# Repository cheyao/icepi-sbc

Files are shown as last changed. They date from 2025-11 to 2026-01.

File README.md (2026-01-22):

# Icepi SBC

A low-cost single-board computer for the H3 CPU: A cheap yet powerful Linux device that you can take anywhere.

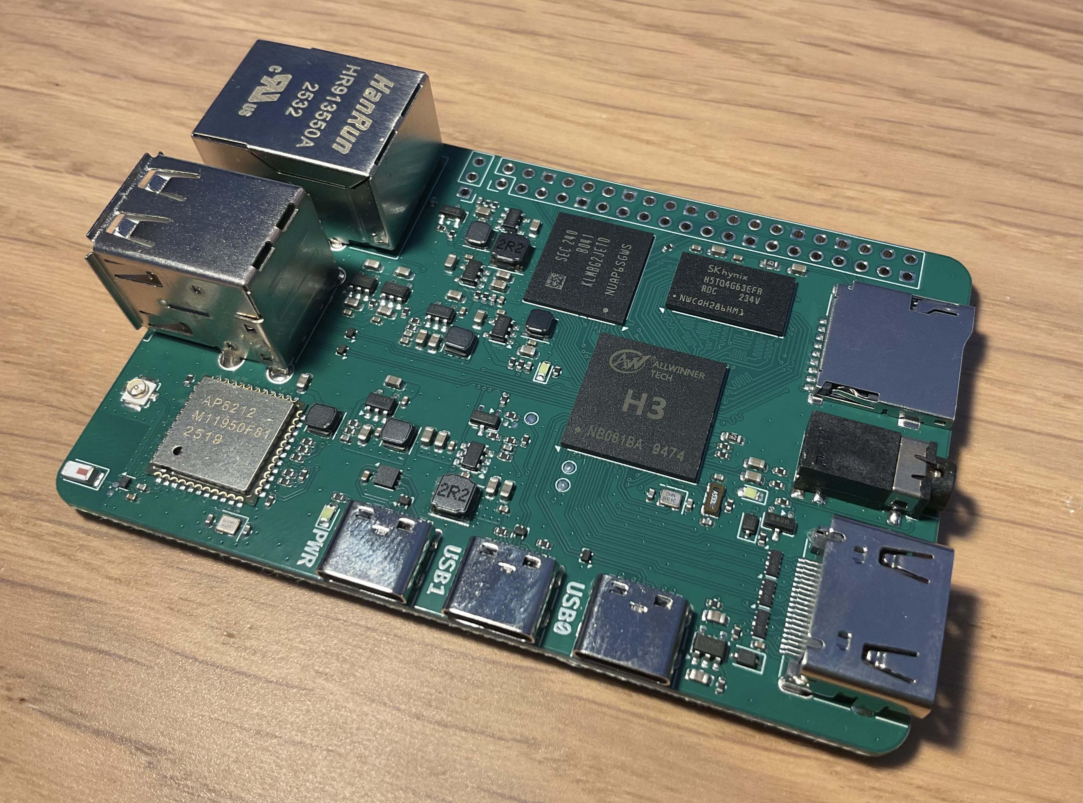
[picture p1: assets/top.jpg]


| Interested? [Subscribe to updates!](https://cyao.dev/subscribe.html) | Check out [Icepi Zero](https://github.com/cheyao/icepi-zero) too |
| --- | --- |

If there's a lot of people interested, there's a chance that I'll try to sell this at a relatively low price :P

## Features

- H3 Quad-Core ARM Cortex-A7 @ 1.296GHz CPU
    - Mali400 MP2 OpenGL ES 2.0 GPU
- 512MiB of DDR3 RAM, stable at 696MHz (Upgradable to 1GiB)
- Ethernet PHY, WiFi & Bluetooth
- GPDI video out
- USB connectors:
    - 2x USB-A 
    - 2x USB-C (One OTG port)
    - 1x USB-C 100W PD power port
- 3.5mm audio jack
- uSD card slot
- eMMC 5.1 storage



## System support

The single-board computer is capable of running Linux (debian) and Android ([H3Droid](https://h3droid.com/project)). It can output 4k video via it's GPDI-A connector, output a tty consol via UART, or act as an remote host via ssh.

It's small, compact form factor allows it to be a nice portable computer that you can take anywhere! It supports GPU acceleration and 4k video decoding, letting you view anything in full confort.

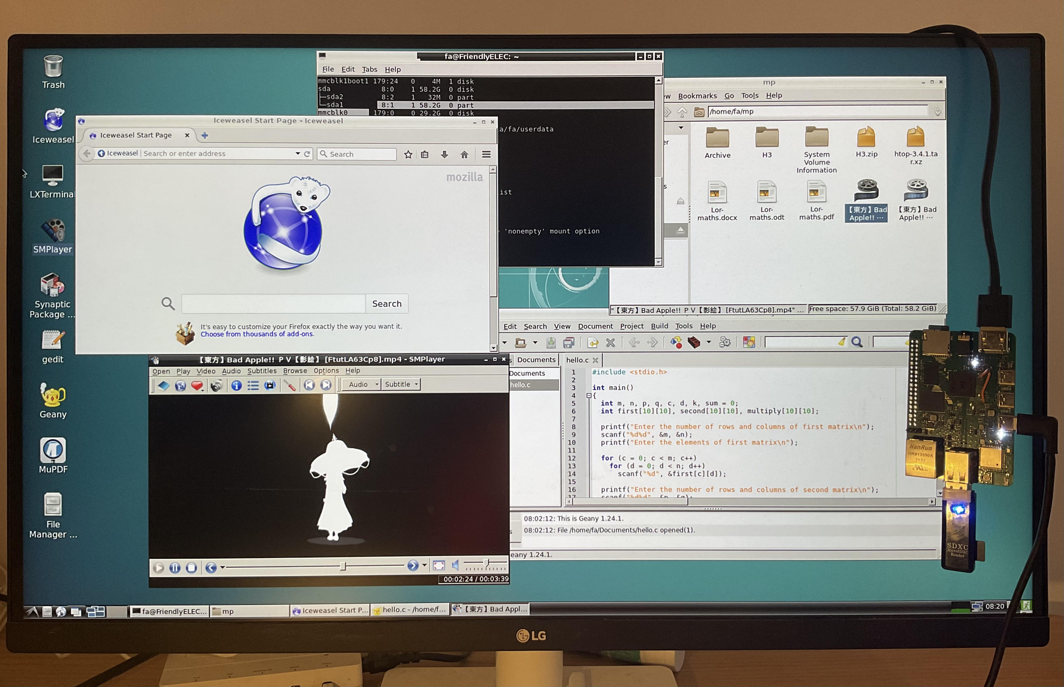
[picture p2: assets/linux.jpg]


## PCB

[Check out the online version here](https://github.com/cheyao/icepi-sbc/tree/main/hardware).

The PCB is only 4 layered, ensuring minimal cost and overhead during production. But for mass production 6 layers is recommended, putting solid ground on In.1 and In.4, then copy the power plane to In.2 and In.3. (Impedance matching might be required depending on stackup)

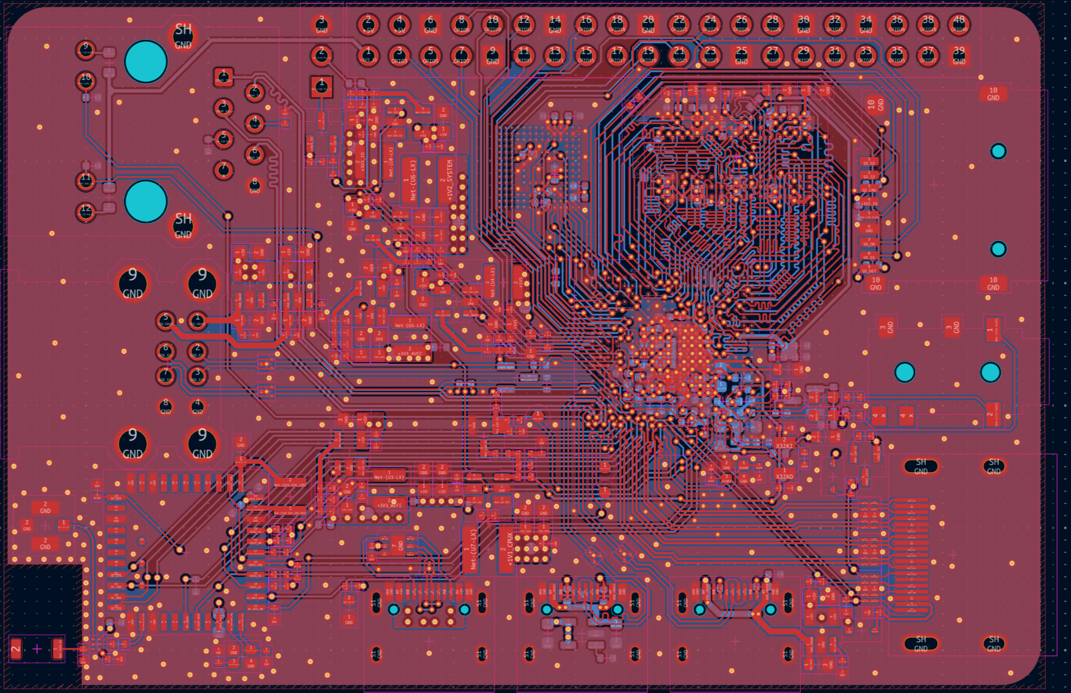
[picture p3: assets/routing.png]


The current setup uses [JLCPCB's](https://jlcpcb.com/) JLC04161H-3313 stackup, and the BOM is optimized for use there. Using other fabs would require re-tuning the DDR3, USB and GPDI traces.

## Open source

This project is licensed under the [Solderpad](/LICENSE) hardware license, granting the maximum amount of liberty :)

It is also OSHWA certified under the identifier [FR000029](https://certification.oshwa.org/fr000029.html).

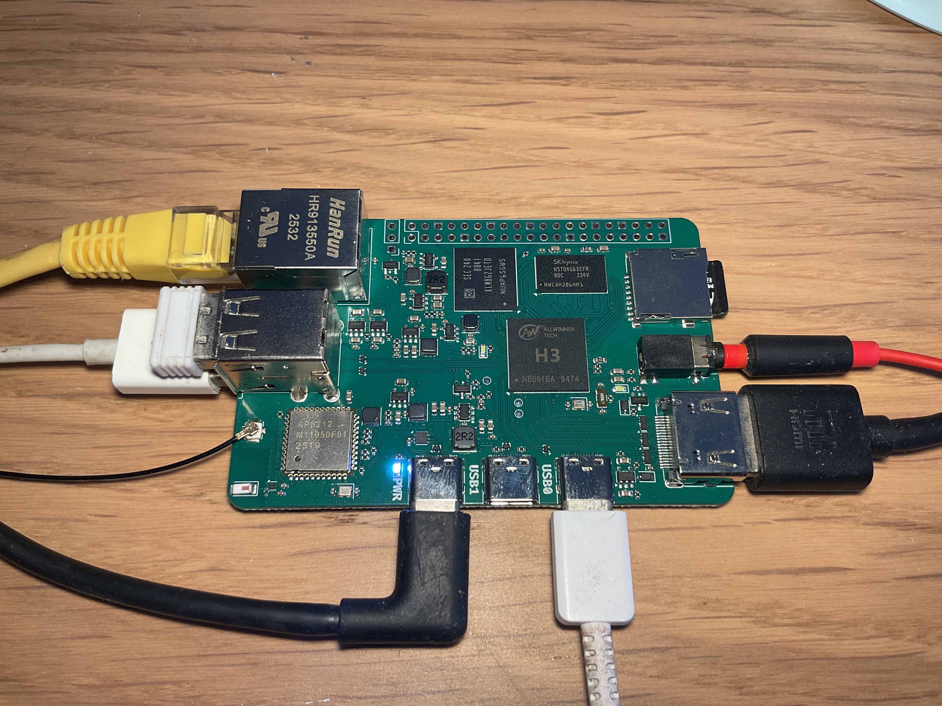
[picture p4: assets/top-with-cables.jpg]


## Contact

Any questions? Dm `@Cyao.` on Discord (Send a friend request or join the KiCAD Discord server) or send an email to `cyao _at_ duck.com`!

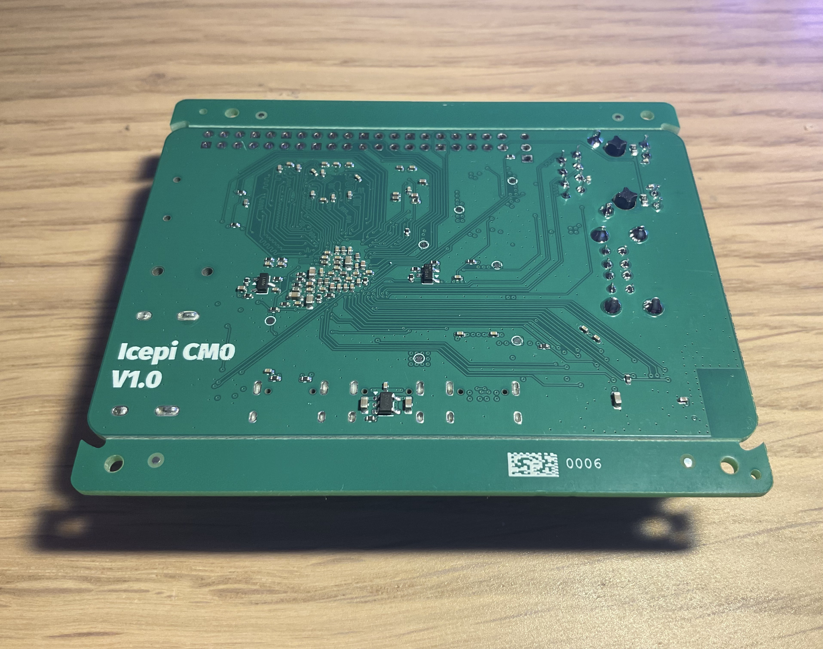
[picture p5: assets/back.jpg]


## Bonus

POV: Running Android on the single board computer to study Eigenvectors in the middle of the night:

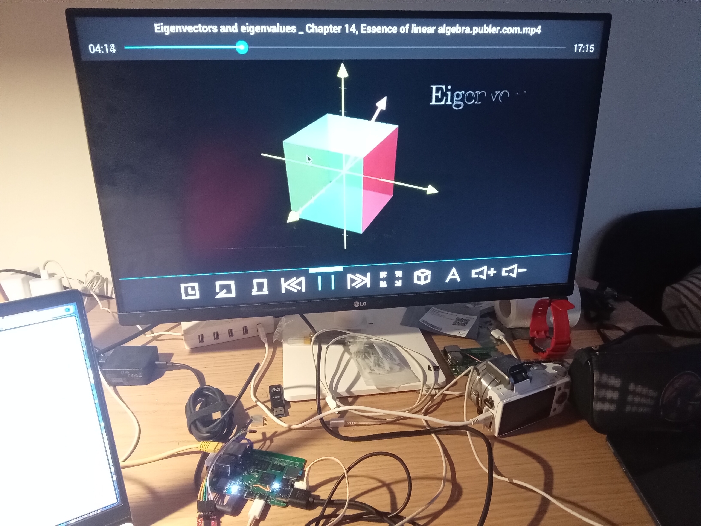
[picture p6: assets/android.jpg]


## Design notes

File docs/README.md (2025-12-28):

# Usage

To power up the board, plug a USB-C cable into the port labeled PWR.

The SBC can boot either from a SD-Card, or the eMMC.

## Linux

This board should be compatiable with the Orange Pi Linux images! But I might make my own Linux image when I get my hands on the boards.

## Android

Check out the https://www.h3droid.com/ project! I'll try and port it over when I have time.

## Debugging

You can find the UART pins on the top-left corner of the PCB, in the up-to-down order of GND, TX, RX.

The CPU's debug software and manual can be downloaded [here](https://mega.nz/folder/dRNDiaLS#P0zxg4pFopMfrBjBBBc2VA).

## More info

You can find more info about the H3 processor here:

https://linux-sunxi.org/H3

## License

The hardware is licensed under the [solderpad](https://solderpad.org/licenses/) license, and the documentation under [zlib](https://en.wikipedia.org/wiki/Zlib_License).

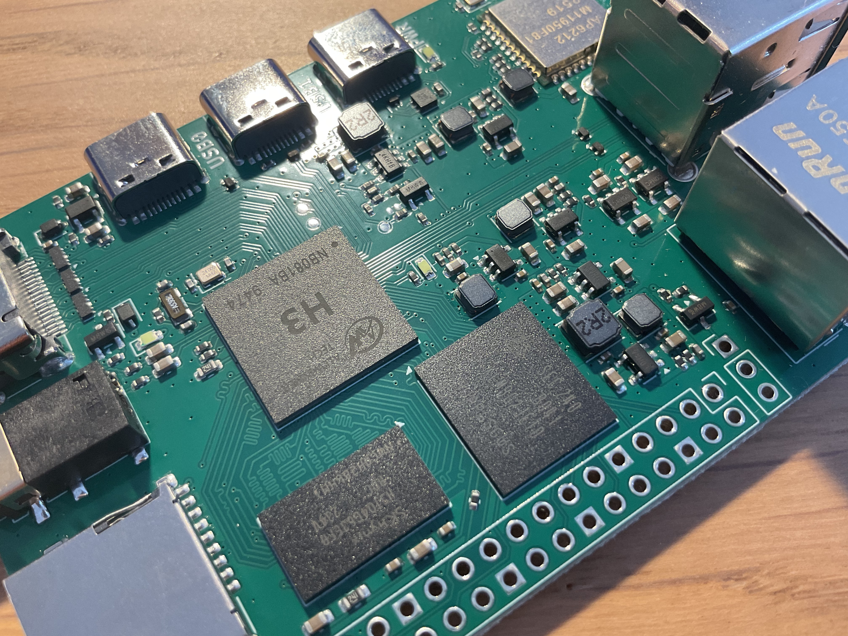
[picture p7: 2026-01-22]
assets/chip-zoom.jpg

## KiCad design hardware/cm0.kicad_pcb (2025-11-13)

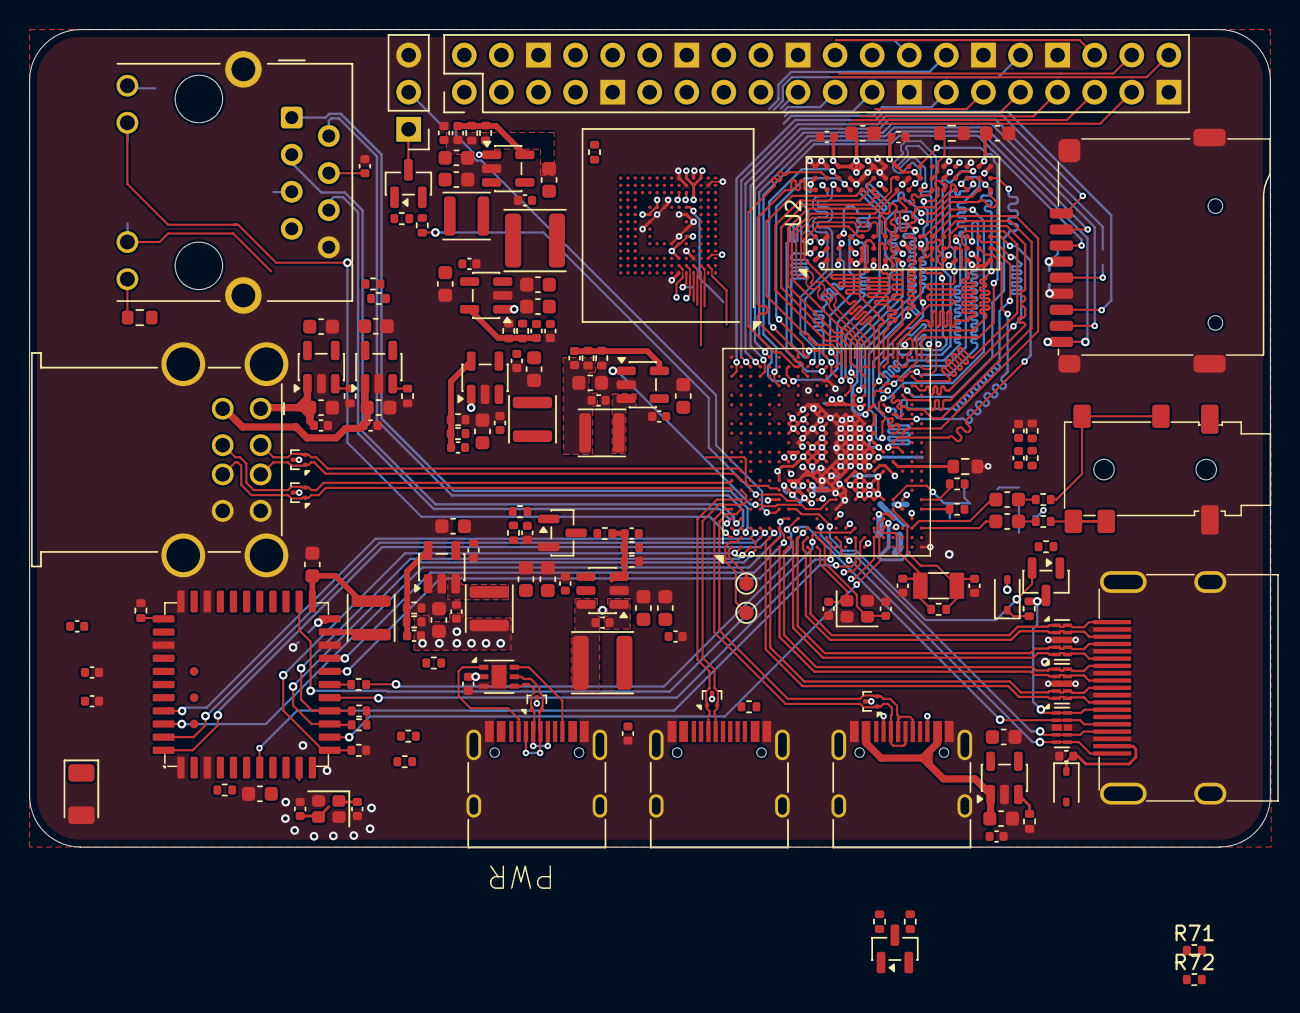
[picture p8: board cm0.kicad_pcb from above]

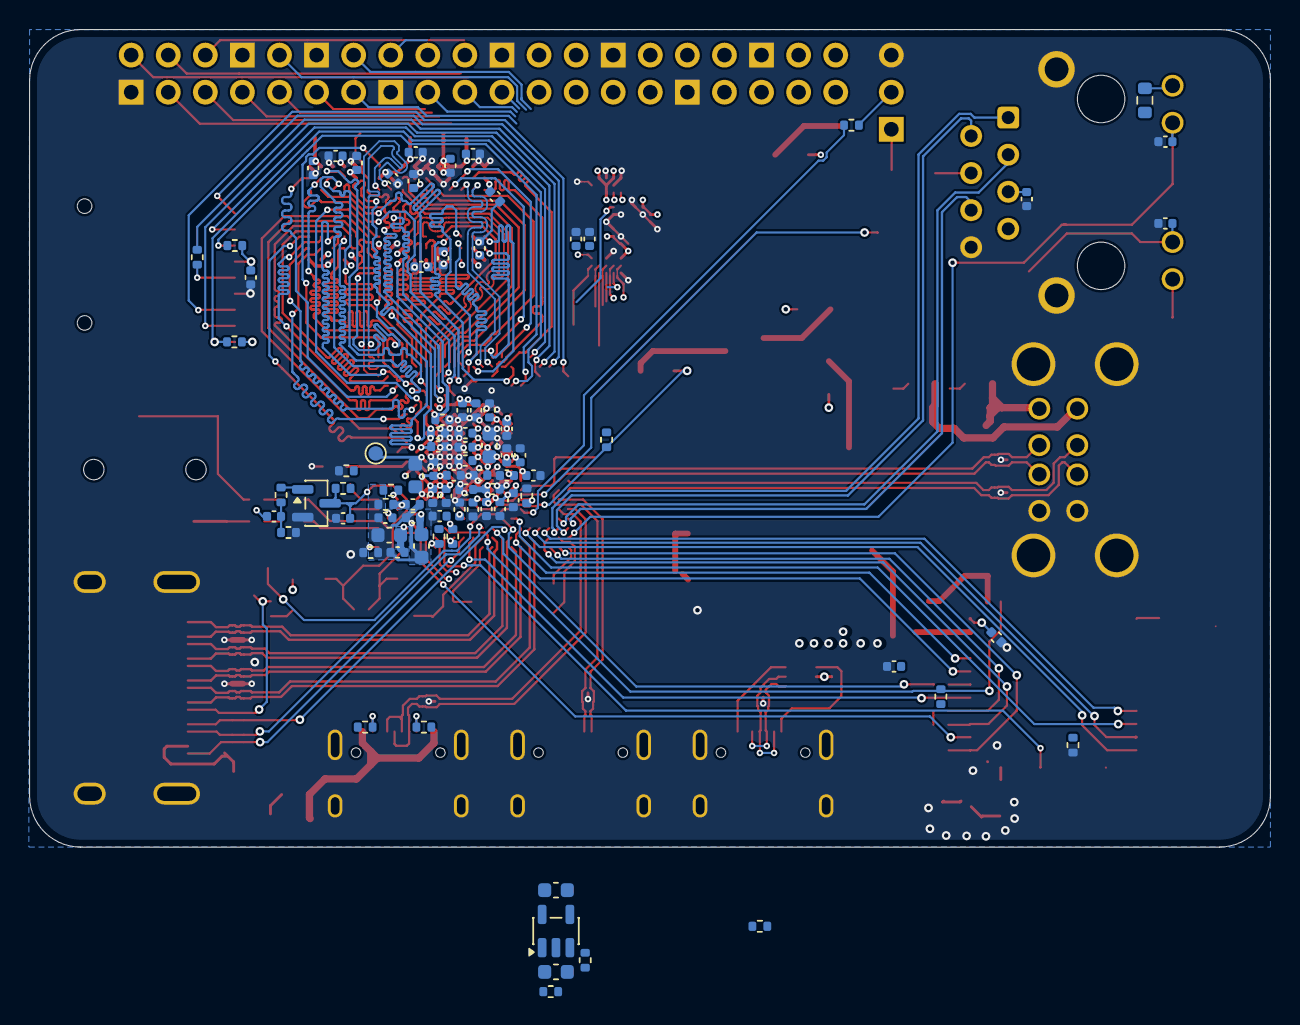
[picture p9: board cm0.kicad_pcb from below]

Board: 4 copper layers, 85.0 x 56.0 mm, 253 parts (85 on the bottom side), 209 nets.

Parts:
AE1: 2450AT18A100E; Johanson_2450AT18x100
C1, C2, C3, C4, C7, C8, C12, C14, C18, C19, C23, C24, C26, C27, C29, C31, C37, C38, C40, C41, C42, C43, C46, C47, C48, C49, C52, C53, C54, C55, C56, C57, C58, C60, C62, C65, C67, C70, C72, C76, C78, C81, C84, C85, C90, C92, C95, C98, C101, C104, C108, C110, C113, C114, C121, C122, C123, C124, C130: 100nF; C_0402_1005Metric
C5, C59, C75, C80, C82, C87, C93: 22uF; C_0603_1608Metric
C10, C11, C32, C129: 4.7uF; C_0402_1005Metric
C13, C16, C17, C21, C22, C25, C33, C35, C36, C45, C51, C107, C109, C111: 1uF; C_0402_1005Metric
C15, C20, C28, C30, C44, C50, C63, C64, C68, C69, C73, C79, C83, C86, C89, C96, C97, C99, C100, C102, C103, C105, C106, C112, C118, C125, C126: 10uF; C_0603_1608Metric
C34, C39, C127, C128: 15pF; C_0402_1005Metric
C61, C66, C71, C77, C88, C91: 22pF; C_0402_1005Metric
C94, C116, C117: NC; C_0402_1005Metric
C115, C119, C120: 10pF; C_0402_1005Metric
D1, D2: 1N5819WS; D_SOD-323
J1: USB_A_Stacked; USB_A_SHOUHAN_AF_SS-JB17.6_Horizontal_Stacked
J2, J3, J4: USB_C_Receptacle_USB2.0_14P; USB_C_Receptacle_HRO_TYPE-C-31-M-12
J5: GPDI_A; GPDI_A_XUNPU_001S
J6: Micro_SD_Card_Det1; microSD_TF-01A
J7: RJ45_Hanrun_HR913550A_Horizontal; RJ45_Hanrun_HR911105A_Horizontal
J8: Conn_01x03; PinHeader_1x03_P2.54mm_Vertical
J9: GPIO; PinHeader_2x20_P2.54mm_Vertical
J10: AudioJack_PJ-342; Jack_3.5mm_SHOUHAN_PJ-342
L1, L2, L3, L6, L7: 2.2uH; L_Sunlord_SWPA3015S
L4, L5: 2.2uH; L_Sunlord_SWPA4030S
Q1, Q3, Q4: BSN20; SOT-23
Q2: AO3415A; SOT-23
Q5: MMBT3904; SOT-23
R1: 6.04k; R_0402_1005Metric
R2, R9, R54, R55: 240; R_0603_1608Metric
R3, R5, R24: 0; R_0402_1005Metric
R4: 220k; R_0402_1005Metric
R6: 10M; R_0402_1005Metric
R7, R8, R39, R40, R71, R72: 2k; R_0402_1005Metric
R10, R11, R12, R15, R16, R20, R23, R25, R31, R32, R33, R36, R41, R45, R51, R56, R63, R64, R65: 10k; R_0402_1005Metric
R13, R17, R26: 2.2k; R_0402_1005Metric
R14: 15k; R_0402_1005Metric
R18, R19, R27, R52, R62, R69, R70: 100k; R_0402_1005Metric
R21: 11.8K; R_0402_1005Metric
R22, R28, R37, R38, R46, R47, R48, R49, R50: 33k; R_0402_1005Metric
R29, R30, R34, R35, R42, R43: 56k; R_0402_1005Metric
R44, R53, R57, R58, R59, R60: 33; R_0402_1005Metric
R61, R66, R67, R68: 47k; R_0402_1005Metric
TP1, TP2, TP3: TestPoint; TestPoint_Pad_D1.0mm
U1: H3; FBGA-347_14x14mm_Layout21x21_P0.65mm
U2: H5TQ4G63EFR; FBGA-96_7.5x13mm_Layout9x16_P0.8mm
U3, U4, U5, U8: SY8088; SOT-23-5
U6: SY8089A; SOT-23-5
U7: SY8113; TSOT-23-6
U9, U10, U11, U12: SY6280AAC; SOT-23-5
U13, U14, U15, U16, U18: TPD2EUSB30; Texas_DRT-3
U17: HUSB237; DFN-6-1EP_2x2mm_P0.65mm_EP1x1.6mm
U19, U20, U23: UCL0524P; Diodes_UDFN-10_1.0x2.5mm_P0.5mm
U21: EMMC5.1_BGA153; LFBGA-153_11.5x13mm_Layout14x14_P0.5mm
U22: AP6212
Y1: 32kHz; Crystal_SMD_3215-2Pin_3.2x1.5mm
Y2: 26MHz; Crystal_SMD_2016-4Pin_2.0x1.6mm
Y3: 24MHz; Crystal_SMD_2016-4Pin_2.0x1.6mm

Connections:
+1V1_CPUX: C15.1, C16.2, C17.2, C18.2, C19.2, C85.2, C86.1, C87.1, L5.2, U1.N8 (VDD-CPUX), U1.P6 (VDD-CPUX), U1.P7 (VDD-CPUX), U1.P8 (VDD-CPUX), U1.P9 (VDD-CPUX), U1.R6 (VDD-CPUX), U1.R7 (VDD-CPUX), U1.R8 (VDD-CPUX), U1.T6 (VDD-CPUX), U1.T7 (VDD-CPUX), U1.T8 (VDD-CPUX), U1.U6 (VDD-CPUX), U1.U9 (VDD-CPUX)
+1V2_SYSTEM: C4.2, C20.1, C21.2, C22.2, C23.2, C24.2, C77.1, C78.2, C79.1, C80.1, L4.2, R18.2, U1.F8 (EPHY_VDD), U1.H10 (VDD-SYS), U1.J10 (VDD-SYS), U1.J11 (VDD-SYS), U1.J12 (VDD-SYS), U1.K10 (VDD-SYS), U1.K11 (VDD-SYS), U1.K12 (VDD-SYS), U1.L10 (VDD-SYS), U1.L11 (VDD-SYS), U1.L12 (VDD-SYS), U1.L13 (VDD-SYS), U1.L14 (VDD-SYS)
+1V5: C35.2, C36.2, C37.2, C38.2, C42.1, C44.1, C45.2, C46.1, C47.1, C48.1, C49.1, C50.1, C51.2, C52.1, C53.1, C54.1, C55.1, C56.1, C57.1, C58.1, C66.1, C67.2, C68.1, L2.2, R7.2, R14.2, U1.L16 (VCC-DRAM), U1.M16 (VCC-DRAM), U1.N16 (VCC-DRAM), U1.P16 (VCC-DRAM), U1.P17 (VCC-DRAM), U1.R16 (VCC-DRAM), U1.T12 (VCC-DRAM), U1.T13 (VCC-DRAM), U1.T14 (VCC-DRAM), U1.T15 (VCC-DRAM), U1.U11 (VCC-DRAM), U2.A1 (VDDQ), U2.A8 (VDDQ), U2.B2 (VDD), U2.C1 (VDDQ), U2.C9 (VDDQ), U2.D2 (VDDQ), U2.D9 (VDD), U2.E9 (VDDQ), U2.F1 (VDDQ), U2.G7 (VDD), U2.H2 (VDDQ), U2.H9 (VDDQ), U2.K2 (VDD), U2.K8 (VDD), U2.N1 (VDD), U2.N9 (VDD), U2.R1 (VDD), U2.R9 (VDD)
+3V3: R41.1, U21.C6 (VCCQ), U21.E6 (VCC), U21.F5 (VCC), U21.J10 (VCC), U21.K9 (VCC), U21.M4 (VCCQ), U21.N4 (VCCQ), U21.P3 (VCCQ), U21.P5 (VCCQ)
+3V3_AVCC: C5.1, C7.2, C12.2, C27.2, C28.1, C29.2, C71.1, C72.2, C73.1, L3.2, Q2.2 (S), R10.1, R11.1, R15.2, R23.1, R61.1, R62.1, R65.1, R66.1, R68.1, U1.G9 (V33_TV), U1.K6 (VCC_RTC), U1.N3 (VCC_PLL), U1.V3 (AVCC)
+3V3_IO: C1.2, C2.2, C3.2, C8.2, C13.2, C14.2, C91.1, C92.2, C93.1, C109.2, C129.1, D1.2 (A), J6.4 (VDD), J9.1, L6.2, Q3.1 (G), Q4.1 (G), R25.2, R37.1, R42.1, R43.1, R54.1, R55.1, R56.1, R67.1, U1.G7 (EPHY_VCC), U1.G11 (VCC_USB), U1.G13 (VCC-IO), U1.G14 (VCC-IO), U1.G15 (VCC-IO), U1.H7 (VCC-PG), U1.H11 (VDD-EFUSEEBP), U1.H13 (VCC-IO), U1.H14 (VCC-IO), U1.J6 (GPDI_VCC), U1.J14 (VCC-IO), U1.J15 (VCC_PD)
+3V3_WIFI: C61.1, C62.2, C63.1, C112.1, C113.1, C114.1, L1.2, R12.2, R45.1, R46.1, R47.1, R48.1, R49.1, R50.1, R51.1, U22.9 (VBAT), U22.22 (VDDIO)
+5V: C59.1, C60.2, C64.1, C65.2, C69.1, C70.2, C75.1, C76.2, C82.1, C83.1, C84.2, C89.1, C90.2, C97.1, C100.1, C103.1, C106.1, C107.2, D2.2 (A), J4.A4 (VBUS), J4.A9 (VBUS), J4.B4 (VBUS), J4.B9 (VBUS), J9.2, J9.4, R39.2, R40.2, U3.1 (EN), U3.4 (IN), U4.4 (IN), U5.1 (EN), U5.4 (IN), U6.4 (IN), U7.5 (IN), U8.4 (IN), U9.4 (EN), U9.5 (IN), U10.4 (EN), U10.5 (IN), U11.4 (EN), U11.5 (IN), U12.4 (EN), U12.5 (IN), U17.2 (VBUS)
/Audio/AUDIO_L: C126.2, U1.AA3 (LINEOUTL)
/Audio/AUDIO_R: C125.2, U1.Y3 (LINEOUTR)
/Audio/TV_OUT: J10.1, U1.F10 (TVOUT)
/DDR3/A0: U1.T17 (SA0), U2.N3 (A0)
/DDR3/A1: U1.U18 (SA1), U2.P7 (A1)
/DDR3/A2: U1.V19 (SA2), U2.P3 (A2)
/DDR3/A3: U1.V20 (SA3), U2.N2 (A3)
/DDR3/A4: U1.V21 (SA4), U2.P8 (A4)
/DDR3/A5: U1.Y19 (SA5), U2.P2 (A5)
/DDR3/A6: U1.Y20 (SA6), U2.R8 (A6)
/DDR3/A7: U1.V15 (SA7), U2.R2 (A7)
/DDR3/A8: U1.W18 (SA8), U2.T8 (A8)
/DDR3/A9: U1.Y18 (SA9), U2.R3 (A9)
/DDR3/A10: U1.P19 (SA10), U2.L7 (A10/AP)
/DDR3/A11: U1.N19 (SA11), U2.R7 (A11)
/DDR3/A12: U1.R18 (SA12), U2.N7 (A12/~BC)
/DDR3/A13: U1.V12 (SA13), U2.T3 (A13)
/DDR3/A14: U1.N17 (SA14), U2.T7 (A14)
/DDR3/A15: U1.R17 (SA15), U2.M7 (A15)
/DDR3/BA0: U1.W17 (SBA0), U2.M2 (BA0)
/DDR3/BA1: U1.T18 (SBA1), U2.N8 (BA1)
/DDR3/BA2: U1.V17 (SBA2), U2.M3 (BA2)
/DDR3/CKE: U1.AA21 (SCKE0), U2.K9 (CKE)
/DDR3/CLK+: U1.AA19 (SCK), U2.J7 (CK)
/DDR3/CLK-: U1.AA20 (SCKB), U2.K7 (~CK)
/DDR3/DQ0: U1.T20 (SDQ5), U2.E3 (DQ0)
/DDR3/DQ1: U1.P20 (SDQ2), U2.F7 (DQ1)
/DDR3/DQ2: U1.U19 (SDQ6), U2.F2 (DQ2)
/DDR3/DQ3: U1.N20 (SDQ0), U2.F8 (DQ3)
/DDR3/DQ4: U1.U20 (SDQ7), U2.H3 (DQ4)
/DDR3/DQ5: U1.P21 (SDQ1), U2.H8 (DQ5)
/DDR3/DQ6: U1.U21 (SDQ3), U2.G2 (DQ6)
/DDR3/DQ7: U1.R19 (SDQ4), U2.H7 (DQ7)
/DDR3/DQ8: U1.J21 (SDQ11), U2.D7 (DQ8)
/DDR3/DQ9: U1.M21 (SDQ14), U2.C3 (DQ9)
/DDR3/DQ10: U1.H21 (SDQ10), U2.C8 (DQ10)
/DDR3/DQ11: U1.M19 (SDQ15), U2.C2 (DQ11)
/DDR3/DQ12: U1.J19 (SDQ8), U2.A7 (DQ12)
/DDR3/DQ13: U1.L21 (SDQ13), U2.A2 (DQ13)
/DDR3/DQ14: U1.H20 (SDQ9), U2.B8 (DQ14)
/DDR3/DQ15: U1.L20 (SDQ12), U2.A3 (DQ15)
/DDR3/DQM0: U1.M20 (SDQM0), U2.E7 (LDM)
/DDR3/DQM1: U1.G20 (SDQM1), U2.D3 (UDM)
/DDR3/DQS0+: U1.R20 (SDQS0), U2.F3 (LDQS)
/DDR3/DQS0-: U1.R21 (SDQS0B), U2.G3 (~LDQS)
/DDR3/DQS1+: U1.K20 (SDQS1), U2.C7 (UDQS)
/DDR3/DQS1-: U1.J20 (SDQS1B), U2.B7 (~UDQS)
/DDR3/ODT: U1.W11 (SODT0), U2.K1 (ODT)
/DDR3/~CAS: U1.U15 (SCAS), U2.K3 (~CAS)
/DDR3/~CS: U1.W20 (SCS0), U2.L2 (~CS)
/DDR3/~RAS: U1.V13 (SRAS), U2.J3 (~RAS)
/DDR3/~RESET: U1.U16 (SRST), U2.T2 (~RESET)
/DDR3/~WE: U1.W13 (SWE), U2.L3 (~WE)
/GPDI/GPDI_CEC: Q3.2 (S), R37.2, U1.G5 (GPDI_CEC)
/GPDI/GPDI_CECI: J5.13 (CEC), Q3.3 (D), R38.2, U23.1, U23.10
/GPDI/GPDI_CLK+: J5.10 (CK+), U1.F2 (GPDI_CLK+), U20.4, U20.7
/GPDI/GPDI_CLK-: J5.12 (CK-), U1.E2 (GPDI_CLK-), U20.5, U20.6
/GPDI/GPDI_D0+: J5.7 (D0+), U1.G1 (GPDI_D0+), U20.1, U20.10
/GPDI/GPDI_D0-: J5.9 (D0-), U1.F1 (GPDI_D0-), U20.2, U20.9
/GPDI/GPDI_D1+: J5.4 (D1+), U1.H2 (GPDI_D1+), U19.4, U19.7
/GPDI/GPDI_D1-: J5.6 (D1-), U1.G2 (GPDI_D1-), U19.5, U19.6
/GPDI/GPDI_D2+: J5.1 (D2+), U1.J1 (GPDI_D2+), U19.1, U19.10
/GPDI/GPDI_D2-: J5.3 (D2-), U1.J2 (GPDI_D2-), U19.2, U19.9
/GPDI/GPDI_HPD: J5.19 (HPD), U1.M2 (GPDI_HPD), U23.5, U23.6
/GPDI/GPDI_SCL: J5.15 (SCL), R40.1, U1.H3 (GPDI_SCL), U23.2, U23.9
/GPDI/GPDI_SDA: J5.16 (SDA), R39.1, U1.K3 (GPDI_SDA), U23.4, U23.7
/GPIO/CPU_RX: R57.1, U1.H6 (PA5)
/GPIO/CPU_TX: R58.1, U1.F5 (PA4)
/H3/AGND: C28.2, C29.1, C30.2, C31.1, C32.2, C33.1, R4.2, R5.1, U1.U3 (AGND)
/H3/BT_HOST_WAKE: U1.P2 (PL2), U22.7 (BT_HOST_WAKE)
/H3/BT_RXD: U1.D3 (UART1_RX), U22.43 (UART_RXD)
/H3/BT_TXD: U1.G4 (UART1_TX), U22.42 (UART_TXD)
/H3/BT_WAKE: R45.2, R69.1, U1.A13 (PA20), U22.6 (BT_WAKE)
/H3/EPHY_LINK_LED: C124.1, J7.10, U1.A2 (EPHY_LINK_LED)
/H3/EPHY_RX+: J7.3 (RD+), U1.B4 (EPHY_RXP)
/H3/EPHY_RX-: J7.6 (RD-), U1.A4 (EPHY_RXN)
/H3/EPHY_SPD_LED: C123.1, J7.11, U1.F7 (EPHY_SPD_LED)
/H3/EPHY_TX+: J7.1 (TD+), U1.B3 (EPHY_TXP)
/H3/EPHY_TX-: J7.2 (TD-), U1.A3 (EPHY_TXN)
/H3/KEYADC: R62.2, U1.AA5 (KEYADC)
/H3/PWR_CPUFB: C88.1, R20.1, TP1.1, U1.T10 (VDD-CPUFB)
/H3/PWR_DRAM: R10.2, U1.M6 (PL9), U4.1 (EN)
/H3/PWR_IO: Q2.1 (G), R27.2, U1.R2 (PL5)
/H3/PWR_KEY: R66.2, U1.R1 (PL3)
/H3/PWR_SYSTEM: R11.2, U1.T2 (PL8), U6.1 (EN), U7.4 (EN)
/H3/PWR_VSET: R24.2, U1.T4 (PL6)
/H3/RECOVERY: R68.2, U1.N2 (PL4)
/H3/RESET: C130.2, Q5.3 (C), R65.2, U1.V6 (RESET)
/H3/SDIO_CLK: R53.1, U1.J3 (SDC1_CLK)
/H3/SDIO_CMD: R50.2, U1.L2 (SDC1_CMD), U22.16 (SDIO_DATA_CMD)
/H3/SDIO_D0: R49.2, U1.H4 (SDC1_D0), U22.18 (SDIO_DATA_0)
/H3/SDIO_D1: R48.2, U1.F3 (SDC1_D1), U22.19 (SDIO_DATA_1)
/H3/SDIO_D2: R47.2, U1.C2 (SDC1_D2), U22.14 (SDIO_DATA_2)
/H3/SDIO_D3: R46.2, U1.C1 (SDC1_D3), U22.15 (SDIO_DATA_3)
/H3/SD_CLK: R44.1, U1.D20 (PF2)
/H3/SD_CMD: J6.3 (CMD), R42.2, U1.F18 (PF3)
/H3/SD_D0: J6.7 (DAT0), U1.A19 (PF1)
/H3/SD_D1: J6.8 (DAT1), U1.D19 (PF0)
/H3/SD_D2: J6.1 (DAT2), U1.C20 (PF5)
/H3/SD_D3: J6.2 (DAT3/CD), U1.E21 (PF4)
/H3/SD_DET: J6.9 (DET), R43.2, U1.G18 (PF6)
/H3/UBOOT: R67.2, U1.W6 (UBOOT)
/H3/USB_D0+: J2.A7 (D-), J2.B7 (D-), U1.A5 (USB_D0+), U13.1 (D+)
/H3/USB_D0-: J2.A6 (D+), J2.B6 (D+), U1.B5 (USB_D0-), U13.2 (D-)
/H3/USB_D1+: J3.A7 (D-), J3.B7 (D-), U1.B6 (USB_D1+), U15.1 (D+)
/H3/USB_D1-: J3.A6 (D+), J3.B6 (D+), U1.B7 (USB_D1-), U15.2 (D-)
/H3/USB_D2+: J1.7 (D2+), U1.A7 (USB_D2+), U14.1 (D+)
/H3/USB_D2-: J1.6 (D2-), U1.A8 (USB_D2-), U14.2 (D-)
/H3/USB_D3+: J1.3 (D1+), U1.B8 (USB_D3+), U16.1 (D+)
/H3/USB_D3-: J1.2 (D1-), U1.B9 (USB_D3-), U16.2 (D-)
/H3/VRA1: C33.2, U1.Y4 (VRA1)
/H3/VRA2: C32.1, R4.1, U1.W5 (VRA2)
/H3/VRP: C30.1, C31.2, U1.V4 (VRP)
/H3/WIFI_32K: R51.2, U1.P3 (X32KFOUT), U22.24 (LPO)
/H3/WL_HOST_WAKE: U1.T3 (PL7), U22.13 (WL_HOST_WAKE)
/H3/WL_REG_ON: R52.1, U1.B1 (PG13), U22.12 (WL_REG_ON)
/H3/X24MI: C127.1, U1.K2 (X24MIN), Y3.2
/H3/X24MO: C128.1, U1.K1 (X24MOUT), Y3.4
/H3/X32KI: C34.1, R6.1, U1.V5 (X32KIN), Y1.2
/H3/X32KO: C39.1, R6.2, U1.U4 (X32KOUT), Y1.1
/H3/eMMC_CLK: U1.A17 (PC5), U21.M6 (CLK)
/H3/eMMC_CMD: R41.2, U1.E16 (PC6), U21.M5 (CMD)
/H3/eMMC_D0: U1.B18 (PC8), U21.A3 (DAT0)
/H3/eMMC_D1: U1.C17 (PC9), U21.A4 (DAT1)
/H3/eMMC_D2: U1.D17 (PC10), U21.A5 (DAT2)
/H3/eMMC_D3: U1.C18 (PC11), U21.B2 (DAT3)
/H3/eMMC_D4: U1.B17 (PC12), U21.B3 (DAT4)
/H3/eMMC_D5: U1.B19 (PC13), U21.B4 (DAT5)
/H3/eMMC_D6: U1.F17 (PC14), U21.B5 (DAT6)
/H3/eMMC_D7: U1.C19 (PC15), U21.B6 (DAT7)
/H3/~BT_CTS: U1.E3 (UART1_CTS), U22.44 (UART_CTS_N)
/H3/~BT_RST: R70.1, U1.D13 (PA9), U22.34 (BT_RST_N)
/H3/~BT_RTS: U1.C3 (UART1_RTS), U22.41 (UART_RTS_N)
/H3/~eMMC_RST: U1.H16 (PC16), U21.K5 (~RST)
/USB/PWR_CC1: J4.A5 (CC1), U17.1 (CC1)
/USB/PWR_CC2: J4.B5 (CC2), U17.6 (CC2)
/USB/PWR_D+: J4.A6 (D+), J4.B6 (D+), U17.4 (D+), U18.1 (D+)
/USB/PWR_D-: J4.A7 (D-), J4.B7 (D-), U17.5 (D-), U18.2 (D-)
/USB/USB_VBUS0: C95.2, C96.1, J2.A4 (VBUS), J2.A9 (VBUS), J2.B4 (VBUS), J2.B9 (VBUS), R29.1, R30.1, U9.1 (OUT)
/USB/USB_VBUS1: C104.2, C105.1, J3.A4 (VBUS), J3.A9 (VBUS), J3.B4 (VBUS), J3.B9 (VBUS), R34.1, R35.1, U12.1 (OUT)
/USB/USB_VBUS2: C98.2, C99.1, J1.1 (VBUS1), U10.1 (OUT)
/USB/USB_VBUS3: C101.2, C102.1, J1.5 (VBUS2), U11.1 (OUT)
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

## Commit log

2025-10-31 Routed DDR3
    [cm0.kicad_pcb, cpu.kicad_sch, untitled.kicad_sch]
2025-11-02 Drew wifi, GPDI, and re-routed DDR3
    [cm0.kicad_pcb, cm0.kicad_sch, cpu.kicad_sch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]
2025-11-05 Added TVS diodes, RF switch and changed RJ45 conn
    [cm0.kicad_pcb, cm0.kicad_sch, cpu.kicad_sch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]
2025-11-09 Drew most of DC DC converters
    [cm0.kicad_pcb, cm0.kicad_sch, cpu.kicad_sch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]
2025-11-12 Laid out the DCDC bucks
    [cm0.kicad_pcb, gpio.kicad_sch]
2025-11-13 Even more routing
    [cm0.kicad_pcb, cpu.kicad_sch, ddr3.kicad_sch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]
2025-11-14 Less than 100 traces left
    [cpu.kicad_sch, storage.kicad_sch, wifi.kicad_sch]
2025-11-18 Improve routing and add test pads
    [audio.kicad_sch, ddr3.kicad_sch, gpio.kicad_sch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]
2025-11-19 Production ready
    [cpu.kicad_sch, ddr3.kicad_sch, gpdi.kicad_sch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]
2025-11-24 Improve heat dissipation and layout
    [audio.kicad_sch, cpu.kicad_sch, gpio.kicad_sch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]
2025-12-05 Add some more decoupling and move trace
    [bom.csv, cpu.kicad_sch, ddr3.kicad_sch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]
2026-01-09 Pretty up schematic
    [ddr3.kicad_sch, storage.kicad_sch, wifi.kicad_sch]
